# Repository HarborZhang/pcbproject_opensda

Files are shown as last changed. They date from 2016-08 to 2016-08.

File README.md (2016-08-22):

# OpenSDA PCB

REV A

摘自Freescale官方开发板上的OpenSDA电路，使用KiCad画板，并测试通过。

1、PCB的gerber文件可以直接发厂家做板子。

2、PCB焊接完成后，安装git和python2.7，使用git从以下地址下载开源启动程序。[https://github.com/mbedmicro/CMSIS-DAP]

3、安装Keil MDK v4打开CMSIS-DAP中mk20的Bootloader程序进行编译，并烧录到该板子中。

4、按住板子上的按键，用usb线链接板子与pc，出现名为MBED的文件夹，将CMSIS-DAP中mk20的Interface程序编译出来bin文件拖拽到MBED文件夹中，重新断电再上电。

5、从以下地址下载CMSIS-DAP驱动。[http://developer.mbed.org/media/downloads/drivers/mbedWinSerial_16466.exe]

6、完成后OpenSDA即可作为CMSIS-DAP烧录器使用。

## 也可在Segger网站下载Jlink对应的v2版本的bin文件在上述步骤4中拖拽，即可作为Jlink使用，但不推荐此方法，该方法被限制只能烧录Freescale的芯片！

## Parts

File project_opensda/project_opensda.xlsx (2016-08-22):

 |  |  |  |  |  |  | Board Qty: | 100
 |  |  |  |  |  |  | Total Cost: | $0.00 |  |  |  | $0.00 |  |  |  |  |  | $0.00 |  |  |  |  |  | $0.00
 |  |  |  |  |  |  | Unit Cost: | $0.00
Global Part Info |  |  |  |  |  |  |  |  | Digi-Key |  |  |  |  |  | Mouser |  |  |  |  |  | Newark
Refs | Value | Desc | Footprint | Manf | Manf# | Qty | Unit$ | Ext$ | Avail | Purch | Unit$ | Ext$ | Cat# | Doc | Avail | Purch | Unit$ | Ext$ | Cat# | Doc | Avail | Purch | Unit$ | Ext$ | Cat# | Doc
R6 | 220R |  | Resistors_SMD:R_0603_HandSoldering |  |  | 100 | $0.00 | $0.00
D3,D4 | BAT54C |  | TO_SOT_Packages_SMD:SOT-23_Handsoldering |  |  | 200 | $0.00 | $0.00
D1 | TVLS14302AC0 |  | miscellaneous:TVLS14302AC0 |  |  | 100 | $0.00 | $0.00
R2,R3 | 33R |  | Resistors_SMD:R_0603_HandSoldering |  |  | 200 | $0.00 | $0.00
C4,C5 | 22pF |  | Capacitors_SMD:C_0603_HandSoldering |  |  | 200 | $0.00 | $0.00
U1 | MK20DX128VFM5 |  | Housings_DFN_QFN:QFN-32-1EP_5x5mm_Pitch0.5mm |  |  | 100 | $0.00 | $0.00
C9,C10 | 10uF |  | Capacitors_SMD:C_0805_HandSoldering |  |  | 200 | $0.00 | $0.00
R12 | 20M |  | Resistors_SMD:R_0603_HandSoldering |  |  | 100 | $0.00 | $0.00
P1 | USB_MICRO |  | Connect:USB_Mini-B |  |  | 100 | $0.00 | $0.00
P2 | CONN_02X05 |  | Pin_Headers:Pin_Header_Straight_2x05 |  |  | 100 | $0.00 | $0.00
R5,R9 | 4.7K |  | Resistors_SMD:R_0603_HandSoldering |  |  | 200 | $0.00 | $0.00
C7 | 2.2uF |  | Capacitors_SMD:C_0603_HandSoldering |  |  | 100 | $0.00 | $0.00
P3 | CONN_02X05 |  | Pin_Headers:Pin_Header_Straight_2x05 |  |  | 100 | $0.00 | $0.00
C2,C6,C8 | 1uF |  | Capacitors_SMD:C_0603_HandSoldering |  |  | 300 | $0.00 | $0.00
SW1 | SW_PUSH |  | miscellaneous:SW_SWD_2PINS |  |  | 100 | $0.00 | $0.00
C3 | 0.1uF |  | Capacitors_SMD:C_0603_HandSoldering |  |  | 100 | $0.00 | $0.00
U2 | 74LVC125ADB |  | SMD_Packages:SSOP-14 |  |  | 100 | $0.00 | $0.00
Y1 | 8MHz |  | miscellaneous:SMD5032_4PINS |  |  | 100 | $0.00 | $0.00
U3 | NCP1117ST33T3G |  | TO_SOT_Packages_SMD:SOT-223 |  |  | 100 | $0.00 | $0.00
C1 | 10uF |  | Capacitors_SMD:C_0603_HandSoldering |  |  | 100 | $0.00 | $0.00
R1,R4,R7,R8,R10,R11 | 10K |  | Resistors_SMD:R_0603_HandSoldering |  |  | 600 | $0.00 | $0.00
L1,L2 | 330R | 磁珠 | Resistors_SMD:R_0805_HandSoldering |  |  | 200 | $0.00 | $0.00
TP1-TP10 | TEST_POINT |  | miscellaneous:TEST_POINT |  |  | 1000 | $0.00 | $0.00
D2 | LED |  | Capacitors_SMD:C_0805_HandSoldering |  |  | 100 | $0.00 | $0.00

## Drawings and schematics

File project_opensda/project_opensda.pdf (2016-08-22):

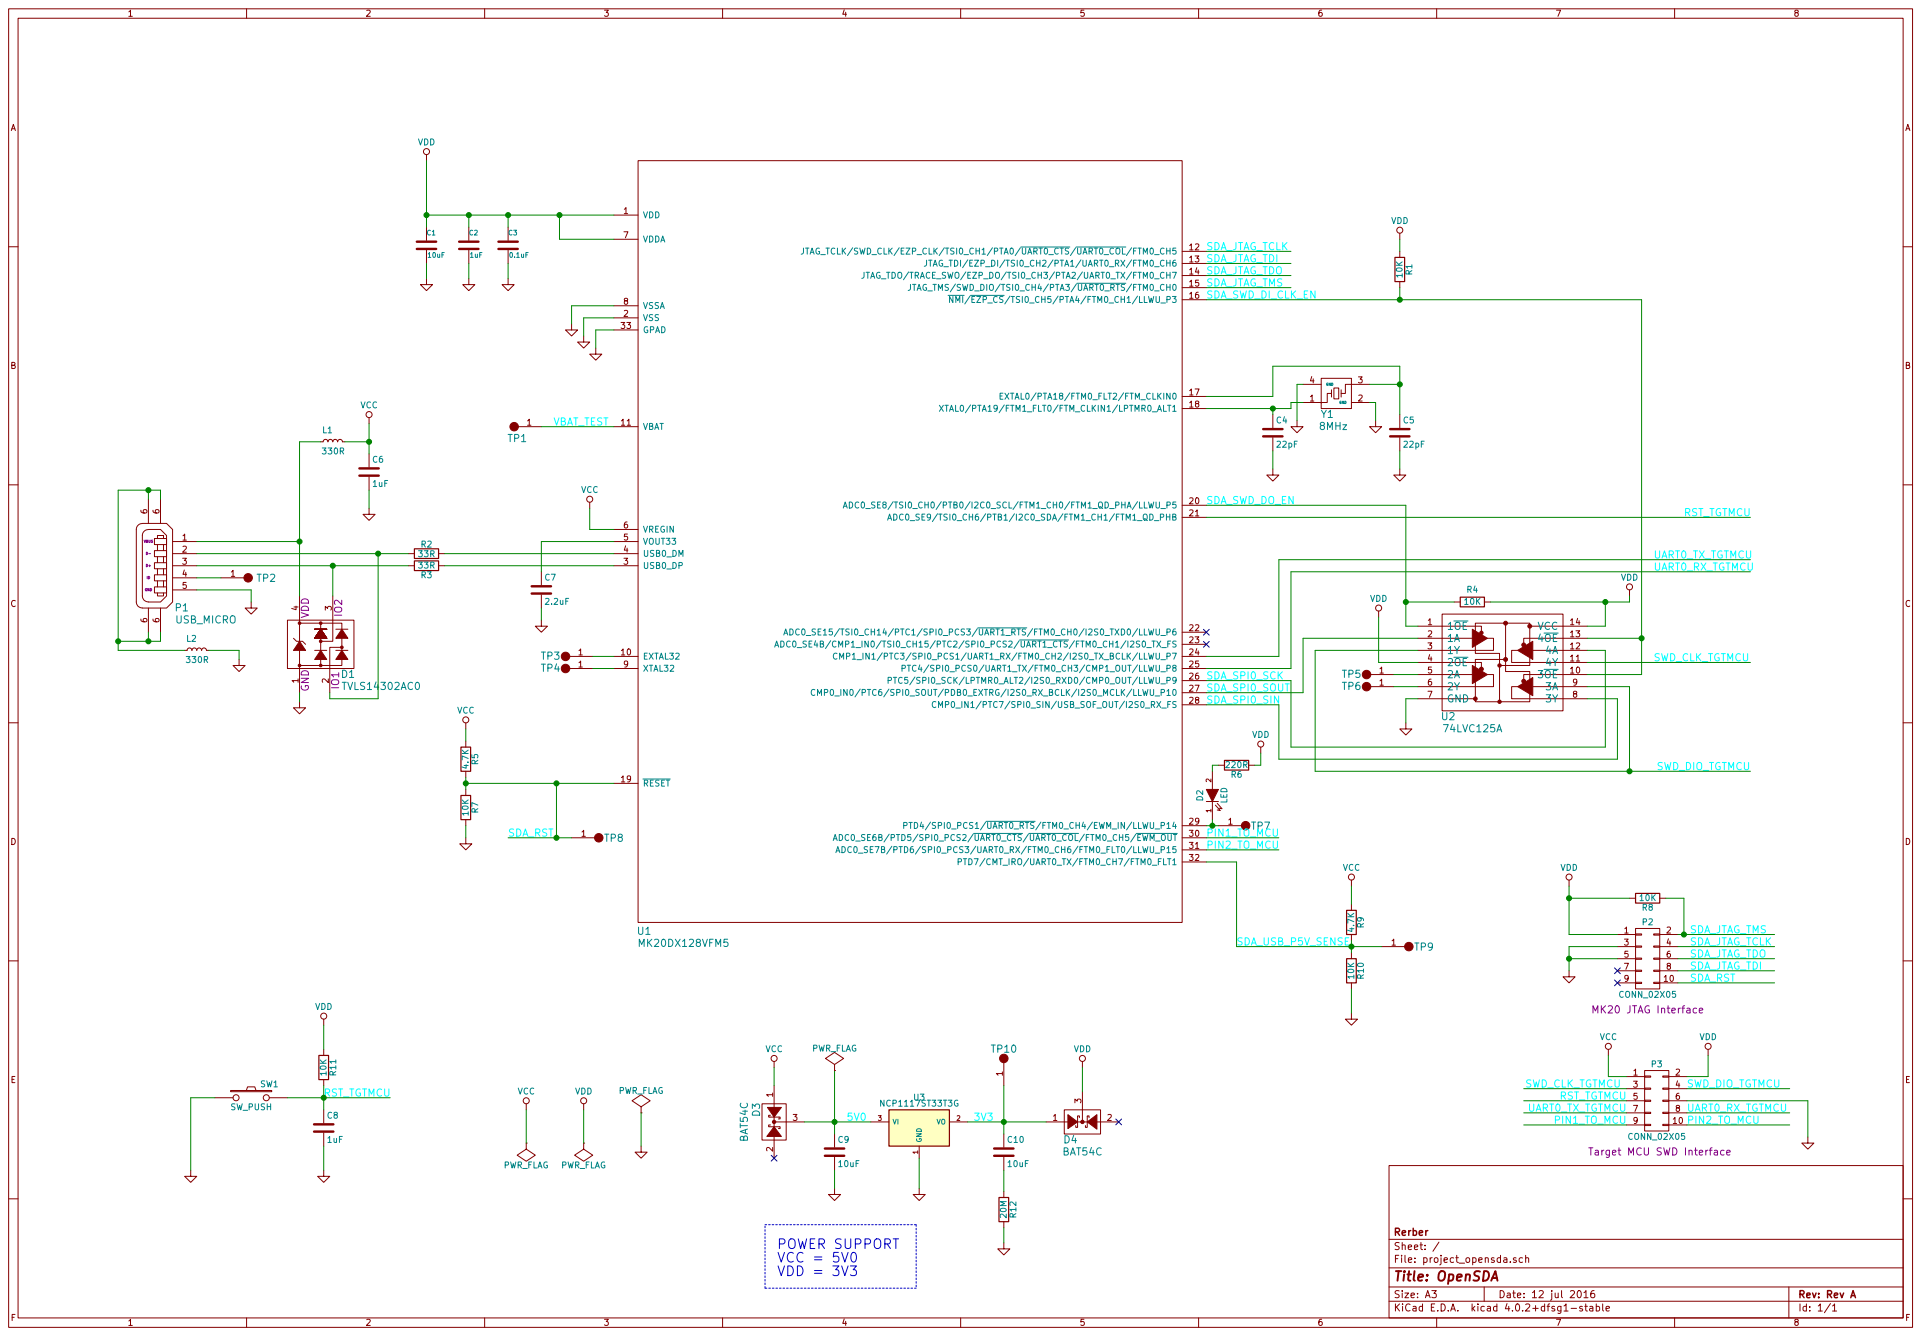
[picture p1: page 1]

SDA_JTAG_TDI
SDA_JTAG_TDO

SDA_SPI0_SCK
SDA_SPI0_SOUT
SDA_SPI0_SIN

File: project_opensda.sch Sheet: / Rerber

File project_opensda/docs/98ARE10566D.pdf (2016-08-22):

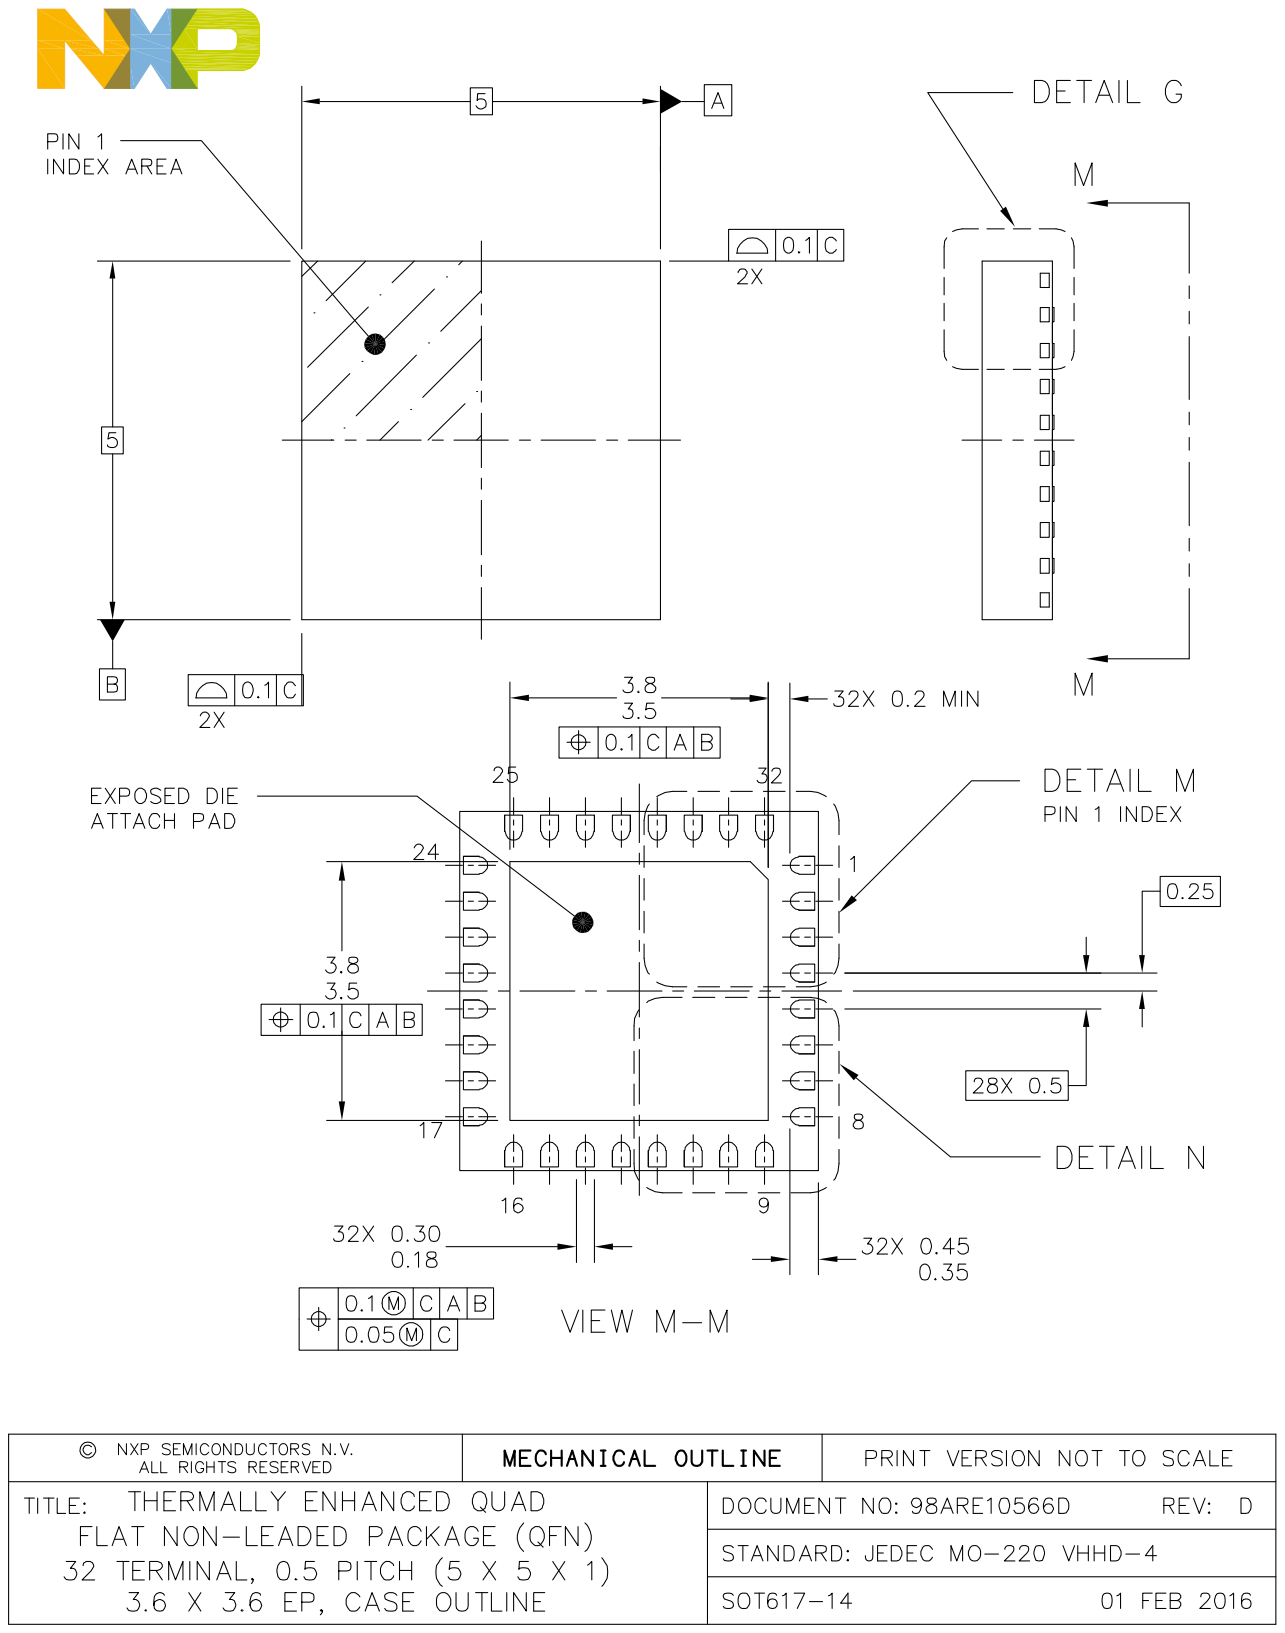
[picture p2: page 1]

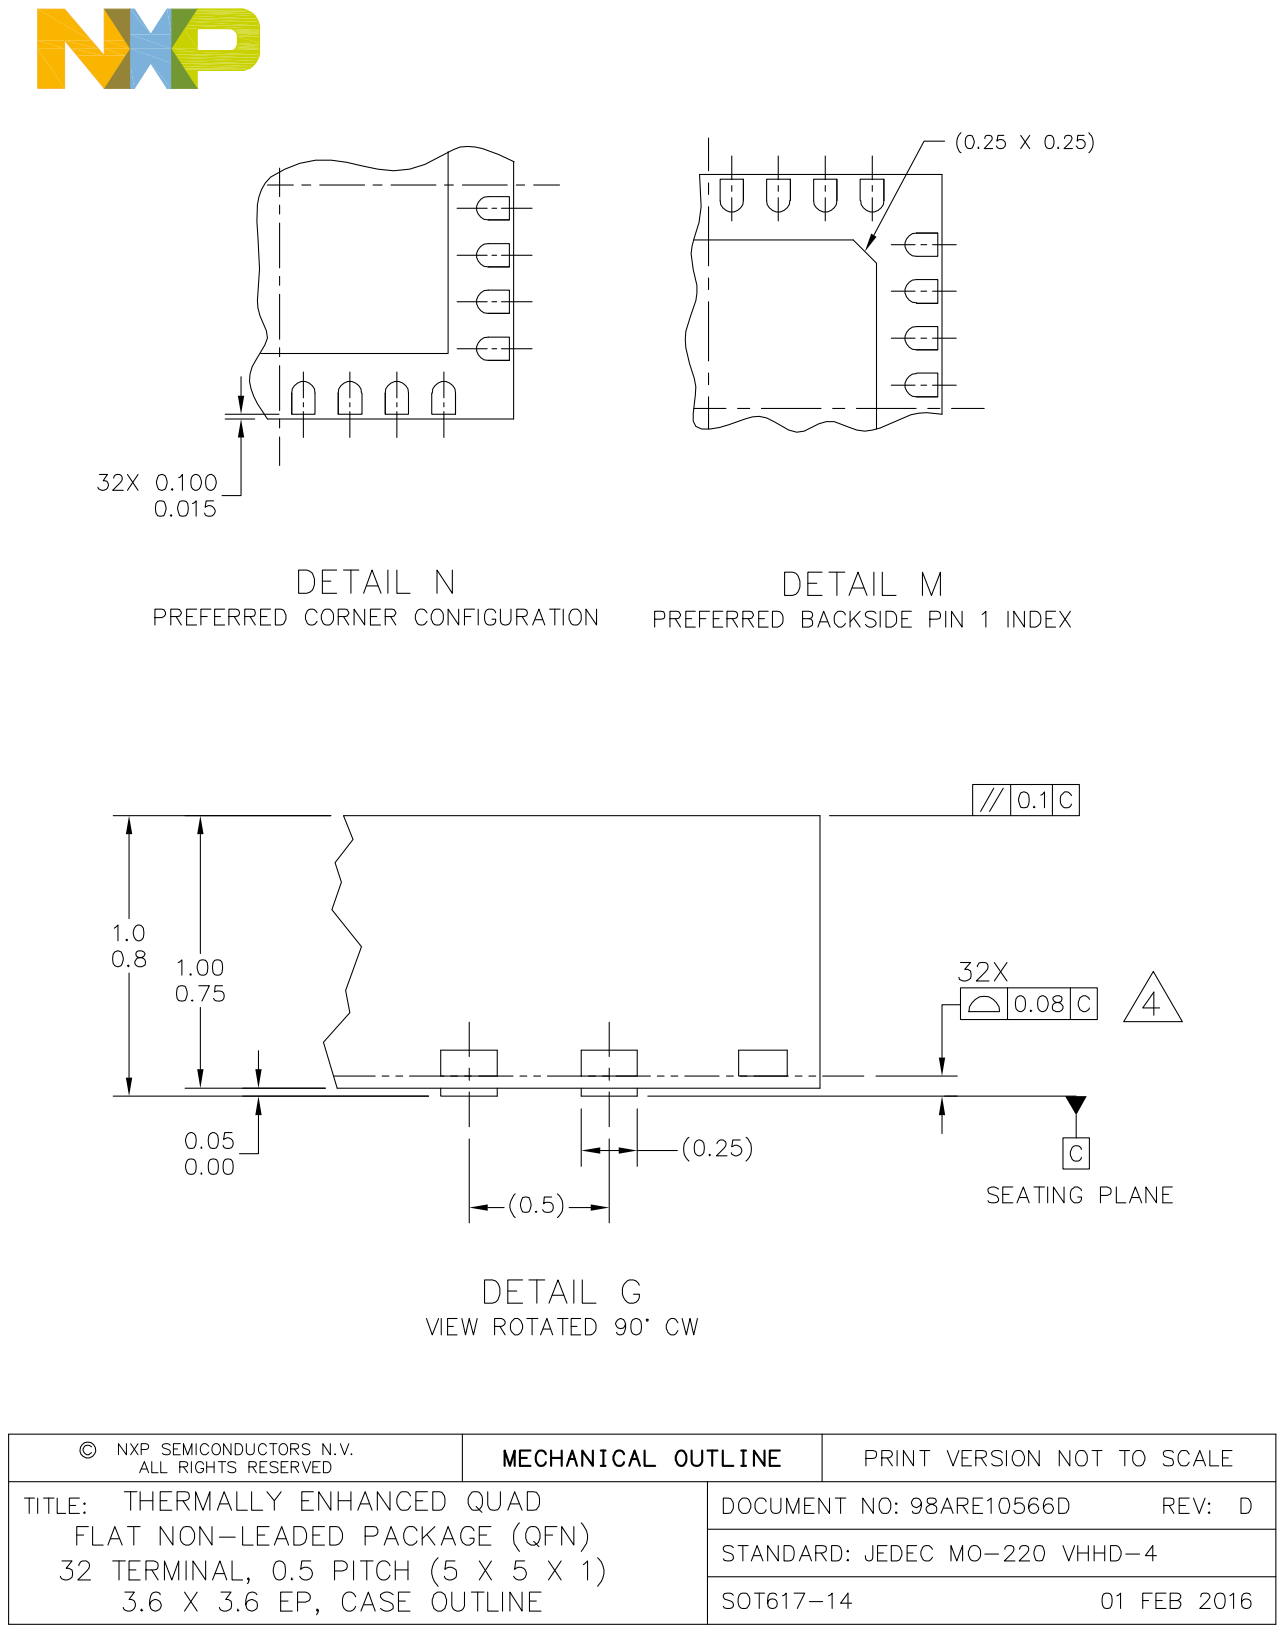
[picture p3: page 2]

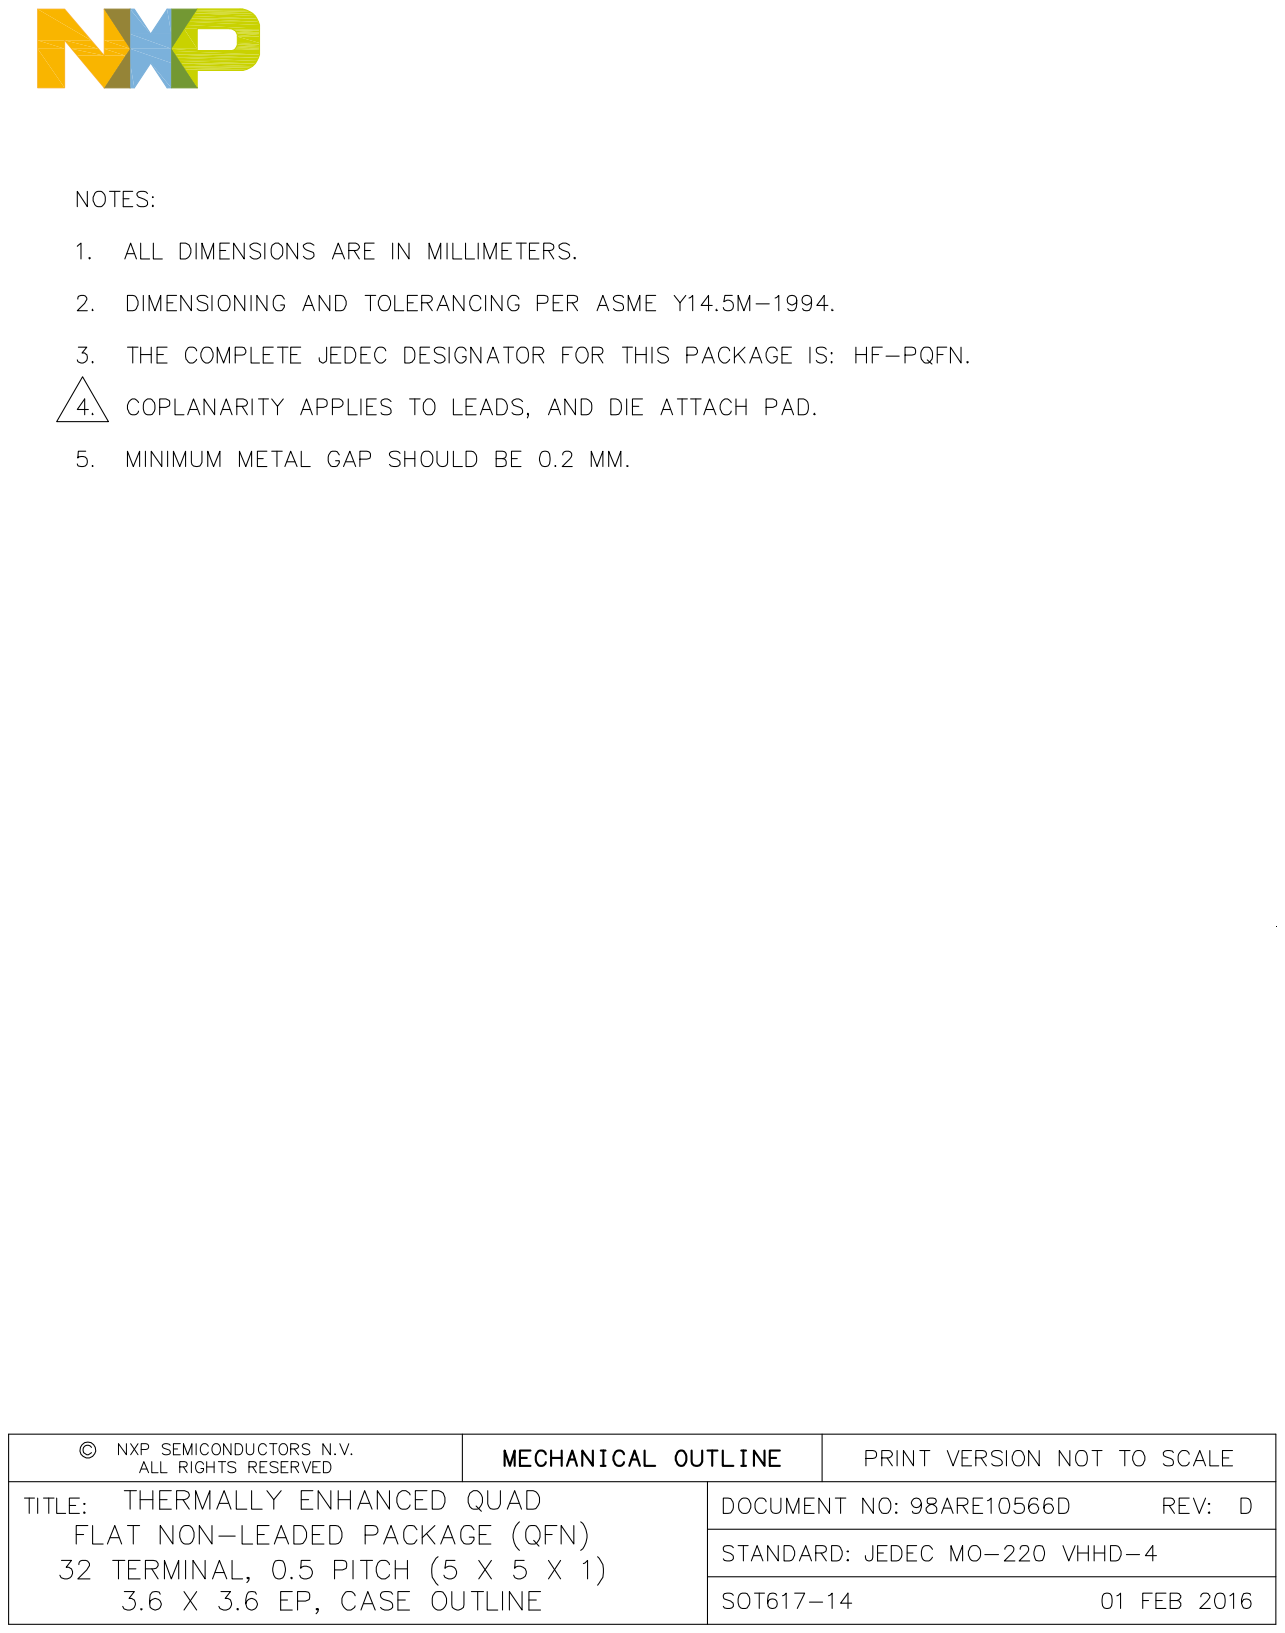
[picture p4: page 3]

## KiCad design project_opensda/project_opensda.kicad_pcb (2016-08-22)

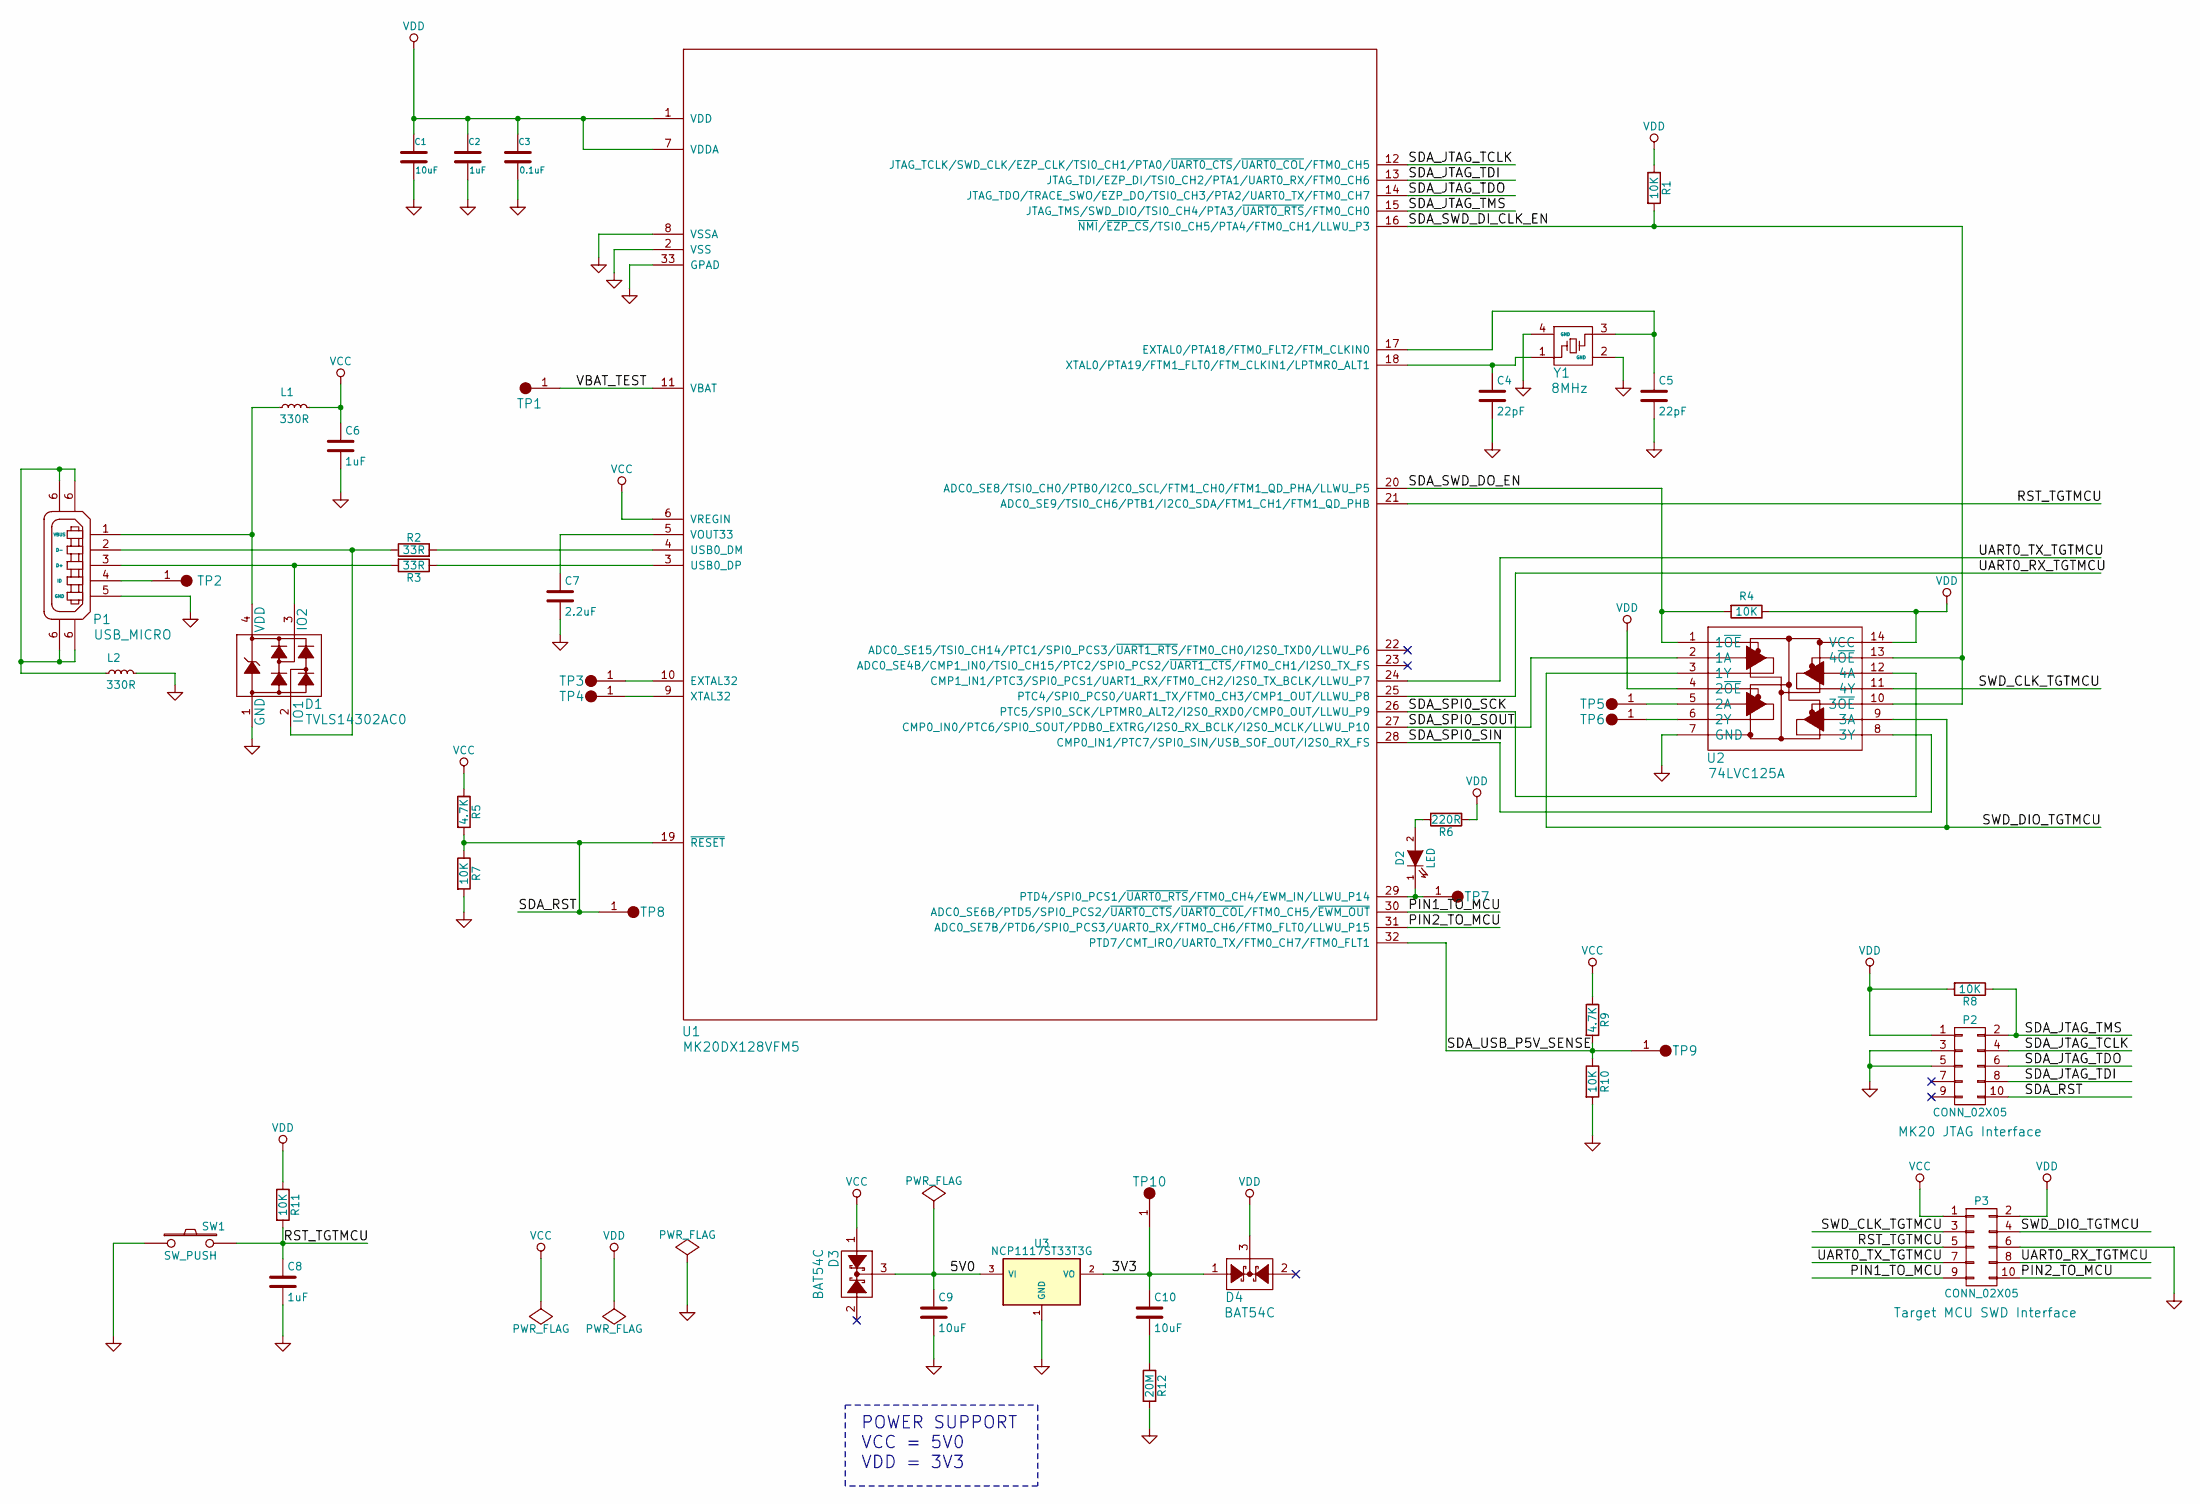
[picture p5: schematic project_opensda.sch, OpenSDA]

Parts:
C1: 10uF; C_0603_HandSoldering
C2, C6, C8: 1uF; C_0603_HandSoldering
C3: 0.1uF; C_0603_HandSoldering
C4, C5: 22pF; C_0603_HandSoldering
C7: 2.2uF; C_0603_HandSoldering
C9, C10: 10uF; C_0805_HandSoldering
D1: TVLS14302AC0
D2: LED; C_0805_HandSoldering
D3, D4: BAT54C; SOT-23_Handsoldering
L1, L2: 330R; R_0805_HandSoldering
P1: USB_MICRO; USB_Mini-B
P2, P3: CONN_02X05; Pin_Header_Straight_2x05
R1, R4, R7, R8, R10, R11: 10K; R_0603_HandSoldering
R2, R3: 33R; R_0603_HandSoldering
R5, R9: 4.7K; R_0603_HandSoldering
R6: 220R; R_0603_HandSoldering
R12: 20M; R_0603_HandSoldering
SW1: SW_PUSH; SW_SWD_2PINS
TP1, TP2, TP3, TP4, TP5, TP6, TP7, TP8, TP9, TP10: TEST_POINT
U1: MK20DX128VFM5; QFN-32-1EP_5x5mm_Pitch0.5mm
U2: 74LVC125A; SSOP-14
U3: NCP1117ST33T3G; SOT-223
Y1: 8MHz; SMD5032_4PINS

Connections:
/3V3: C10.1, D4.1, TP10.1, U3.2 (VO)
/5V0: C9.1, D3.3, U3.3 (VI)
/PIN1_TO_MCU: P3.9, U1.30 (ADC0_SE6B/PTD5/SPI0_PCS2/~UART0_CTS~/~U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)
/PIN2_TO_MCU: P3.10, U1.31 (ADC0_SE7B/PTD6/SPI0_PCS3/UART0_RX/FTM0_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)
/RST_TGTMCU: C8.1, P3.5, R11.2, SW1.2, U1.21 (ADC0_SE9/TSI0_CH6/PTB1/I2C0_SDA/FTM1_CH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)
/SDA_JTAG_TCLK: P2.4, U1.12 (JTAG_TCLK/SWD_CLK/EZP_CLK/TSI0_CH1/PTA0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)
/SDA_JTAG_TDI: P2.8, U1.13 (JTAG_TDI/EZP_DI/TSI0_CH2/PTA1/UART0_RX/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)
/SDA_JTAG_TDO: P2.6, U1.14 (JTAG_TDO/TRACE_SWO/EZP_DO/TSI0_CH3/PTA2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)
/SDA_JTAG_TMS: P2.2, R8.1, U1.15 (JTAG_TMS/SWD_DIO/TSI0_CH4/PTA3/~UART0_R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)
/SDA_RST: P2.10, R5.2, R7.1, TP8.1, U1.19 (~RESET)
/SDA_SPI0_SCK: U1.26 (PTC5/SPI0_SCK/LPTMR0_ALT2/I2S0_RXD0/CMP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), U2.12 (4A)
/SDA_SPI0_SIN: U1.28 (CMP0_IN1/PTC7/SPI0_SIN/USB_SOF_OUT/I2S0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), U2.8 (3Y)
/SDA_SPI0_SOUT: U1.27 (CMP0_IN0/PTC6/SPI0_SOUT/PDB0_EXTRG/I2S0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), U2.2 (1A)
/SDA_SWD_DI_CLK_EN: R1.2, U1.16 (~NMI~/~EZP_CS~/TSI0_CH5/PTA4/FTM0_CH1/L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), U2.10 (3~OE), U2.13 (4~OE)
/SDA_SWD_DO_EN: R4.2, U1.20 (ADC0_SE8/TSI0_CH0/PTB0/I2C0_SCL/FTM1_CH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), U2.1 (1~OE)
/SDA_USB_P5V_SENSE: R9.2, R10.1, TP9.1, U1.32 (PTD7/CMT_IRO/UART0_TX/FTM0_CH7/FTM0_FLT1)
/SWD_CLK_TGTMCU: P3.3, U2.11 (4Y)
/SWD_DIO_TGTMCU: P3.4, U2.3 (1Y), U2.9 (3A)
/UART0_RX_TGTMCU: P3.8, U1.25 (PTC4/SPI0_PCS0/UART1_TX/FTM0_CH3/CMP1_O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)
/UART0_TX_TGTMCU: P3.7, U1.24 (CMP1_IN1/PTC3/SPI0_PCS1/UART1_RX/FTM0_C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)
/VBAT_TEST: TP1.1, U1.11 (VBAT)
GND: C1.2, C2.2, C3.2, C4.2, C5.2, C6.2, C7.2, C8.2, C9.2, D1.1, L2.2, P1.5, P2.3, P2.5, P3.6, R7.2, R10.2, R12.2, SW1.1, U1.2 (VSS), U1.8 (VSSA), U1.33 (GPAD), U2.7 (GND), U3.1 (GND), Y1.2 (GND), Y1.4 (GND)
unnamed: C4.1, U1.18 (XTAL0/PTA19/FTM1_FLT0/FTM_CLKIN1/LPTMR0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), Y1.1
unnamed: C5.1, U1.17 (EXTAL0/PTA18/FTM0_FLT2/FTM_CLKIN0), Y1.3
unnamed: C7.1, U1.5 (VOUT33)
unnamed: C10.2, R12.1
unnamed: D1.2, P1.2, R2.1
unnamed: D1.3, P1.3, R3.2
unnamed: D1.4, L1.1, P1.1
unnamed: D2.1 (K), TP7.1, U1.29 (PTD4/SPI0_PCS1/~UART0_RTS~/FTM0_CH4/EWM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)
unnamed: D2.2 (A), R6.2
unnamed: L2.1, P1.6
unnamed: P1.4, TP2.1
unnamed: R2.2, U1.4 (USB0_DM)
unnamed: R3.1, U1.3 (USB0_DP)
unnamed: TP3.1, U1.10 (EXTAL32)
unnamed: TP4.1, U1.9 (XTAL32)
unnamed: TP5.1, U2.5 (2A)
unnamed: TP6.1, U2.6 (2Y)
VCC: C6.1, D3.1, L1.2, P3.1, R5.1, R9.1, U1.6 (VREGIN)
VDD: C1.1, C2.1, C3.1, D4.3, P2.1, P3.2, R1.1, R4.1, R6.1, R8.2, R11.1, U1.1 (VDD), U1.7 (VDDA), U2.4 (2~OE), U2.14 (VCC)

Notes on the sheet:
POWER SUPPORT VCC = 5V0 VDD = 3V3

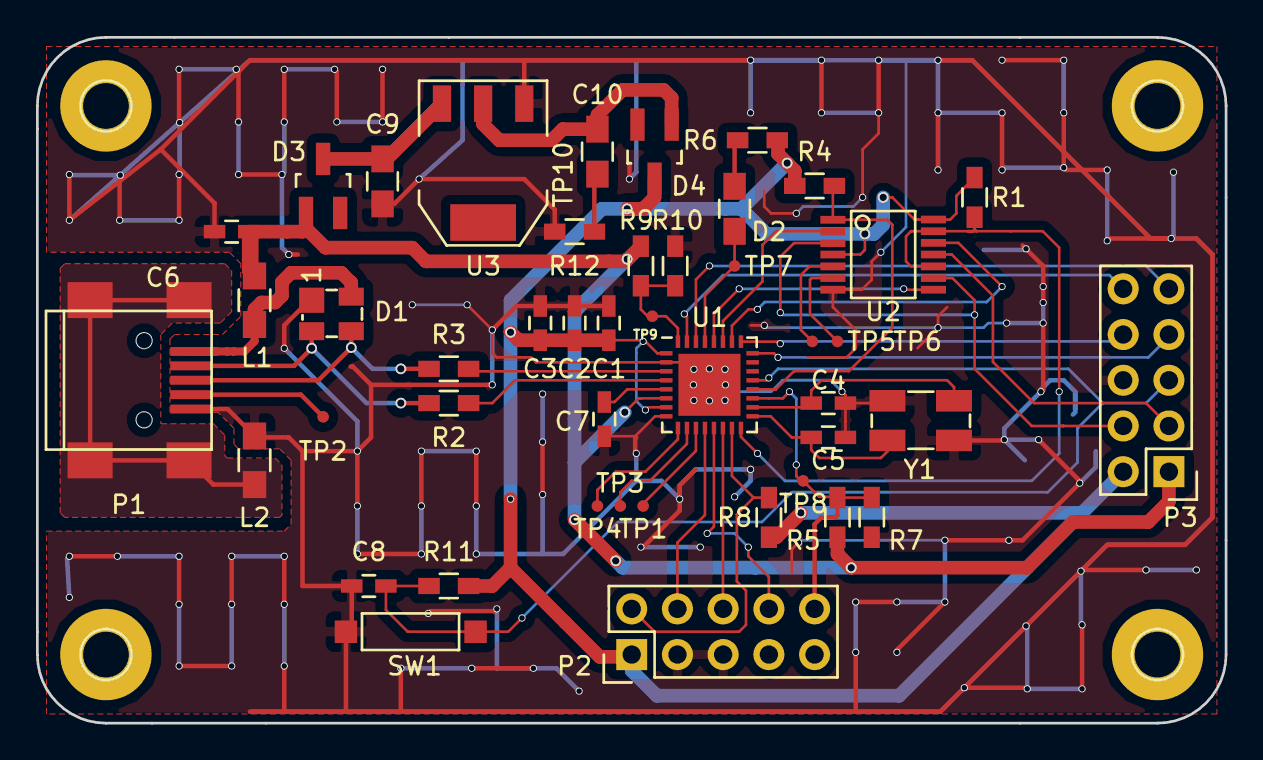
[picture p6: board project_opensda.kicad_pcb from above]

Board: 2 copper layers, 66.0 x 38.1 mm, 46 parts (0 on the bottom side), 41 nets.

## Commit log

2016-08-22 + ‘.sparkleshare’
2016-08-22 add pcb mods
2016-08-22 add pcb files
    [project_opensda-B.Cu.gbr, project_opensda-B.Mask.gbr, project_opensda-B.Paste.gbr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]
